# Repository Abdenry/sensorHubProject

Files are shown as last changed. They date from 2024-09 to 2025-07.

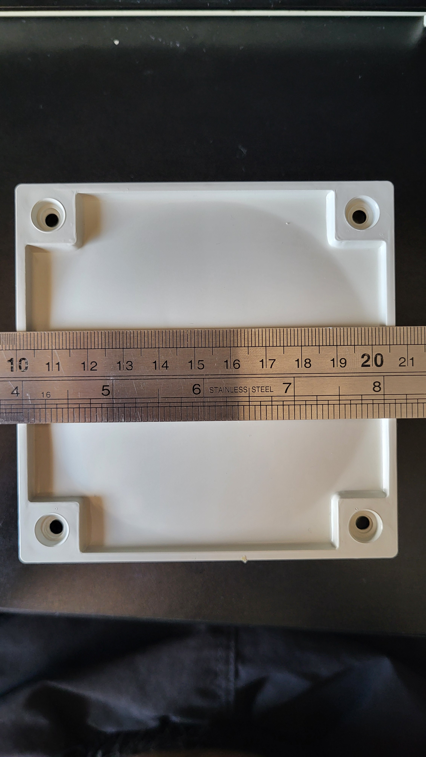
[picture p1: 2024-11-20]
CAD/FreeCAD/weatherStation/components/conduit/box/20241117_103729.jpg

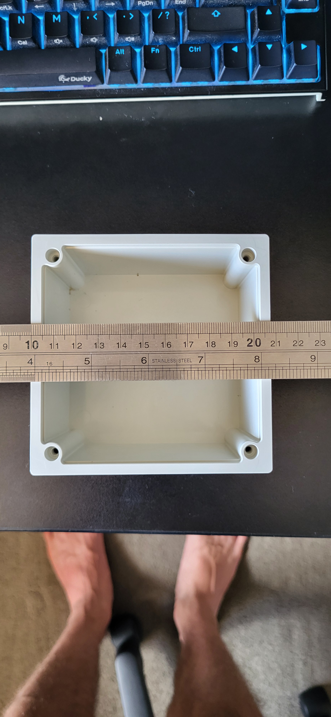
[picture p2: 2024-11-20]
CAD/FreeCAD/weatherStation/components/conduit/box/20241117_102943.jpg

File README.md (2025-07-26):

# Sensor Hub

<p align="center">
  weatherStation
</p>

A small, portable, self-sustaining weather station built to provide data to an external web interface hosted with Grafana via a Raspberry Pi Zero 2 W. This station is able to collect various metrics from on board sensors such as temperature, humidity, heat index, wind speed, and wind direction. A **DHT22** sensor is used to collect relative humidity and temperature metrics with an accuracy of +-2% and +-0.5C, while metrics such as wind speed and wind direction are collected with custom built sensors. The heat index is calculated in software using the [DHT-sensor-library](https://github.com/adafruit/DHT-sensor-library).

Communication is handled through the NRF24l01 radio modules in a mesh configuration. The mesh routing of data packets is automatically managed with `RF24.h`, `RF24Network.h`, and `RF24Mesh.h` provided by the [RF24](https://github.com/nRF24/RF24?tab=readme-ov-file) library, specifically chosen for its meshing capabilities. It provides dynamic configuration of the NRF24l01 modules, meaning that in the scenario where the weather station loses connection with the Raspberry Pi for any reason (power down, range lost, etc.), it can automatically reconfigure and connect to the Raspberry Pi given its under normal operable condition (i.e. has power and is in range). This allows additional stations to be installed with potentially different purposes with all metrics collected to be routed back to the Raspberry Pi. Alternatively, if the distance between the Raspberry Pi and the weather station is much greater than the range of a single NRF24l01 module, an additional node can be configured and placed in between the weather station and Raspberry Pi acting as a range extender. The RF24 library will automatically handle the routing and pass the data collected from the weather station to the Raspberry Pi via that additional node. There is no limitation that prevents an additional station from also being a range extending node.

<p align="center">
  nrf24WeatherStationDiagram4
</p>

### Wiring Diagram
<p align="center">
  circuitDiagram3
</p>

### CAD Model
<p align="center">
  weatherStationCAD
</p>

## Sensor Design
The following sensor assemblies were all 3D printed out of white PET-G filament for its UV resistance, and to reflect as much heat as possible to avoid compromising the temperature and humidity readings of the DHT22 sensor.
### Solar Radiation Shield
The DHT22 sensor used to collect temperature and humidity data was housed in a solar radiation shield. This is necessary to prevent direct sunlight from heating the sensor over time creating higher than ambient temperature readings, simultaneously it protects the sensor from rainfall, which would also cause a higher than ambient humidity reading if it gets wet.

### Wind Vane
Wind direction was measured using eight AH180 omni-polar hall effect sensors and a magnet on the underside of the vane. Each hall effect sensor acts as one of the four cardinal or ordinal directions (North, North East, East, etc.) which is activated only in the presence of the magnet. The vane will point in the direction the wind is blowing **from**. With limited IO available on the Arduino Nano/ATmega328p the SN74HC175N Parallel In Serial Out (PISO) Shift Register was used to reduce the eight outputs of the wind vane to one output + three inputs, halving the total amount of connections to the Arduino Nano/ATmega328p.

<p align="center">
  windVane
</p>

### Anemometer
Wind speed was measured using two magnets and a single US1881 latching hall effect sensor connected to the Arduino Nano D2 pin which corresponds to the ATmega328p external interrupt pin 0 (PD2). The magnets attached to the underside of the anemometer rotate over the US1881 sensor triggering either a high or low state depending on the magnets polarity, generating an interrupt which increments a revolution counter. The `getWindSpeed()` function is called periodically to calculate the wind speed using the amount of revolutions counted within that period, resetting the revolution counter once calculation has completed, and repeats this process. This assembly was tested by having the anemometer attached externally to a moving car, logging its calculated wind speed and comparing it to that the vehicles actual speed. It proved accurate to +-2 km/h with a vehicle speed of 80 km/h.
<p align="center">
  anemometer
</p>

## Grafana Dashboard
The Grafana dashboard conveniently displays historical readings for temperature, humidity, wind speed, and direction. It also provides an updated reading of the stations current temperature, humidity, and calculated heat index. The dashboard has been configured to retain this information for up to two weeks however this can be further increased if desired.
<p align="center">
  dashboard
  successfulTransmission
</p>

## Power Supply and Challenges Faced
Power for the station comes from a 1100 mAh LiPo battery, supported by four 1W solar panels connected in parallel. A solar power manager with Maximum Power Point Tracking (MPPT) is implemented to maximise the efficiency of the solar panels, switching between charging the station and its battery based on sunlight availability. It ensures that the battery remains charged during daylight hours, with enough capacity to keep the station operational overnight. After optimisations, the weather station consumes approximately 0.021 A at 3.72 V, providing an estimated 52 hours of operation without any solar input.

Prior to optimising power consumption, a major challenge faced during development was the intermittent loss of communications particularly over night.

<p align="center">
  dropOuts
</p>

Initially, it was suspected that the issue was not related to power due to the assumption that the 4 watt solar panel array was capable of powering and charging the station which had a measured active consumption of 0.24W (65mA @ 3.7V). After investigating the issue for a significant period of time, no definitive answer could explain the intermittent communication loss overnight other than insufficient solar power. To prove this was the root of the problem the station was connected to a bench top power supply with a constant 3.7V over night. This resulted in no communication drop outs over night nor for the next couple of days as the battery was sufficiently charged from the constant 3.7 V provided by the power supply. Optimisations for the code then proceeded to lower the active consumption.

### Optimisations
The first optimisation was replacing the software timer used to intermittently send weather metrics to the Raspberry Pi to a Watchdog Timer. This did not directly improve the power consumption of the station, however, it would allow the station to wake up from a power down mode, which was the second optimisation performed.

Entering the Arduino Nano/ATmega328p into a power down mode and only powering up after the Watchdog Timer expired directly reduced power consumption from 0.24W (65mA @ 3.7V) to 0.208W (56mA @ 3.7V), a 13% power efficiency improvement.

This was further improved by 64% by powering down the NRF24l01 radio module when not in use. This lowered the active consumption of the station to just 0.0744W (20mA @ 3.7V). This is a total 69% improvement from the initial 0.24W (65mA @ 3.7V) observed prior to optimising.

With the stations active power consumption optimised, the 4W solar panel array was able to sufficiently charge and power the station eliminating the intermittent communication loss.

## Future Improvements
- This station could be improved in the future with the inclusion of a rainfall sensor to collect metrics on the volume and rate of rainfall. One possible design for this sensor could involve a tipping bucket mechanism, where a known volume of rain causes a bucket to tip, triggering a hall-effect sensor to log the event. By counting the frequency of tipping, the system could accurately measure rate and cumulative rainfall over time.
- Improvements could also be made to the assembly of the custom sensors to be more accessible for servicing as the current design is finicky to put together, not suitable for consistently taking apart and putting back together.
- The internal wiring of the station could also be significantly improved by switching the single core wire used for **each** connection, to a multi-core cable. This could make the internal wiring much tidier and easier to access/service.

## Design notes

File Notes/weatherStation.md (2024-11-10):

# Weather Station

The goal is to create an affordable meteorological station for homeowners. This station will enable users to conduct informal studies on local weather patterns, identify optimal gardening techniques, and predict weather events to better prepare for potential threats to their homes.

The station will have a myriad of sensors used to identify the correct weather trends and are listed in detail below. The goal is to construct a weather station for less then cheap commercially [available options](https://www.bunnings.com.au/holman-aspect-wireless-data-centre-weather-station_p3110644).

## Functionality

| Atmospheric Conditions | Sensor |
| --- | --- |
| The weather station shall measure Dry Ambient Temperature. | (ASAIR - AHT20) |
| The weather station shall measure Percent Relative Humidity. | (ASAIR - AHT20) |
| The weather station shall measure Atmospheric Pressure. | (ST - LPS331AP) |

| Wind Measurements | Sensor |
| --- | --- |
| The weather station shall measure Wind Speed. | (Diodes Corporate - AH180) |
| The weather station shall measure Wind Direction. | (Diodes Corporate - AH180) |

| [Precipitation Monitoring](https://smartsolutions4home.com/ss4h-rg-rain-gauge/) | Sensor |
| --- | --- |
| The weather station shall measure Rate of Rainfall. | (Diodes Corporate - AH180) |
| The weather station shall measure Amount of Rainfall. | (Diodes Corporate - AH180) |

| Severe Weather Detection | Sensor |
| --- | --- |
| The weather station should detect lightning strikes. | TBD |

## Design

| Radiation Shield                                                                                                                                                                                                                                                                                                                                                                                                   |
| ------------------------------------------------------------------------------------------------------------------------------------------------------------------------------------------------------------------------------------------------------------------------------------------------------------------------------------------------------------------------------------------------------------------ |
| Both the humidity and temperature sensors will be contained within a radiation shield. This is to prevent direct and indirect heat sources compromising the reliability/accuracy of the senors. It also acts to shield the sensor against rain and fog. [Learn More](https://www.instrumentchoice.com.au/news/instrument-choice-experiment-what-is-the-function-of-a-solar-radiation-shield-on-a-weather-station). |

| Microcontroller                                                                                                                                                                            |
| ------------------------------------------------------------------------------------------------------------------------------------------------------------------------------------------ |
| The microcontroller will be contained in a waterproof container. Any connections made between the microcontroller that is outside the container, will be waterproof and weather resistent. |

| Materials                                                                                                                                                                   |
| --------------------------------------------------------------------------------------------------------------------------------------------------------------------------- |
| Materials used in the design will be durable to the Australia weather. Materials should be UV resistant and should have a heat deflection rating higher than $55\degree$ C. |

| Power |
| ----- |
| A battery will be used to power the device and sensors. The battery will be contained within a water proof container with any connections between it and devices outside the container, waterproof and weather resistent. The battery will be rechargeable via a solar panel mounted to the weather station. |

## Notes

- The chosen [magnets](https://www.digikey.com.au/en/products/detail/radial-magnets-inc/8015/15276818) to be used have been calculated based on the surface Gauss rating and the AH180 operation specs outlined in the datasheet. The information while not rigorous, has been marked against this [calculator](https://www.kjmagnetics.com/calculator.asp?calcType=disc),
  and hand calculated based on the inverse square law. Noting that for both the calculator and [datasheet](https://docs.rs-online.com/c755/0900766b813e101b.pdf) for a similar magnet with a defined Gauss rating at ~1mm. Both seemed to lose ~40% of strength @ 1mm from surface rating.
  Using this as a basis for the chosen magnets it was estimated that at 1mm from surface would have a Gauss rating of ~1335.5, following the inverse square law with this in mind, it was estimated that at 5 mm from the surface of the chosen magnet it would have a strength of ~53.42 Gauss.
  This should be sufficient for the AH180 operation.

- There are two method to measure apparent temperature; one with solar radiance and one without. Both require the dry ambient temperature, the relative humidity percent, and wind speed (m/s). The wind speed needs to be measured at an elevation of 10 meters.

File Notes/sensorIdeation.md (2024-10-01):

# Sensors For Hub
Ideation, hardware, and research for various sensors to potentially be used for the sensorHub project. 

List of sensor ideas:
- Garage Door Sensor
- Outside sensor hub:
   - Barometer
   - Anemometer (Wind Speed Gauge)
   - Temperature Sensor
   - Humidity Sensor
- Moisture Sensor (for plants)
- Daylight sensor
- PC Sensor
- Smart Door Locks
- Water leak sensors

## Garage Door Sensor
Simple sensor that detects if a garage door is currently open or closed. Detection can be achieved via ultrasonic sensor that relays a true or false if the door is open or closed.

## Outside Sensor hub
A hub that can measure the outside temperature, wind speed, humidty and atmospheric pressure.

## Moisture Sensor
A simple sensor that can be used across multiple pot plants or garden beds to determine if watering is needed.

## Daylight Sensor
A simple sensor used to determine if it is day or not. By itself not particularly useful but can be used in conjuction with other devices to turn appliances on/off.

## PC Sensor
A remote switch for a PC that indicates the current state of the PC (on/off) and can be powered on/off remotely.

## Smart Door Locks
A sensor that detects if doors have been locked after you have left the house (Similar to garage door sensor).

## Water leak sensors
Sensors that detect water leakage in areas that are critical and cannot be wet. This can be used in other sensors or appliances around the house.

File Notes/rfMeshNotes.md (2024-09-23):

# [Mesh Networking for RF24 (RF24Mesh)](https://nrf24.github.io/RF24Mesh/md_docs_2general__usage.html)

- Automates the networking process of nrf24 modules
- Assigns nodes a unique number ranging from 1 to 255 (user defined) to act as a static IP
- Addressing, routing, etc. is handled by the library
- Master node keeps track of unique IDs and assigned RF24Network addresses
- Moved or disconnected nodes can automically rejoin the mesh and reconfigure within network
- Uses functionality from RF24 and RF24Network libraries

## [General Usage](https://nrf24.github.io/RF24Mesh/md_docs_2general__usage.html)

### Network Design Options

1. Static Network (no mesh)

   - RF24Network manually configured with static design. RF24Mesh is not used.

2. Static network w/Dynamic Assignment

   - RF24Mesh is only used to acquire an address on startup
   - Nodes are expected to remain stationary
   - Changes to network addressed manually by adding, removing, or resetting nodes
   - Can use the RF24Network functions directly or use RF24Mesh

3. Dynamic Network & Assignment

   - Nodes join the mesh automatically and re-attach as required.
   - Default setting (used for examples)

4. Hybrid Network

   - Utilizes a combination of static & dynamic nodes
   - Requires initlal planning and deployment
   - Can be more stable network easing the use of sleeping nodes

### Network Management

- RF24Network addresses can be viewed as MAC addresses
- RF24Mesh NodeIDs viewed as static IP addresses
- When joining or re-joining network nodes will request a RF24Network address, and are identified via nodeID

#### Raspberry Pi/Linux

- RF24Gateway saves address assignments to file `dhcplist.txt` for restoration even if gateway is restarted
- To force network re-convergence, delete `dhcplist.txt` and restart gateway
- If nodes are configured t overify their connection at set intervals they will come back online in time

#### Arduino/AVR

- Address list is not saved
- To force network re-convergence, restart gateway.
- If nodes are configured t overify their connection at set intervals they will come back online in time
- if node/nodeID is removed permanently, the address hsould be releaser **prior** to removal

### Mesh Communication

- RF24Mesh nodeIDs are unique identifiers
- RF24Network addresses change dynamically within statically defined structure
  - All nodes know the master address (00)
  - The master node maintains a list of all nodes (immediate address lookups)
- Node to Node communication requires address queries to be sent to master node
  - Inheritently inefficient

### Tricks of Trade

- For nodes constantly transmitting (every few seconds at most) it is suitable to check the connection, and/or renew the address when conenctivity fails. Data is not saved by the master node, if the master node goes down, all child nodes must renew their address. In this case, as long as the master node is down for a few seconds, the nodes will all begin requesting an address.
- Nodes not actively transmitting, should be configured to test their connection at predefined intervals to allow them to reconnect as necessary
- Sleeping nodes (nodes only temporarily online) should release their address prior to going offline and request a new one upon waking. _(Note: This can take 10 - 15 ms, up to a few seconds)_
- When transmitting payloads without the network returning a ack-response, nodes should be configured to periodically check connection using `RF24Mesh::checkConnection()`

### RF24Network

Beyond requesting and releasing addresses, usage is outlined in the [RF24Mesh class documentation](https://nrf24.github.io/RF24Mesh/annotated.html), and further information regarding RF24Network is available at [RF24Network documentation](https://nrf24.github.io/RF24Network/index.html).

## [Setup and Config](https://nrf24.github.io/RF24Mesh/md_docs_2setup__config.html)

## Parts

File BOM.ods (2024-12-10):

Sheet: Master Node
Sensor Hub: Bill of Materials
Master Node
Part # | Part Name | Quantity | Units Per Package | Part Description | Package | Vendor | Vendor SKU | Lead Time | Vendor Link | Datasheet | Unit Cost | Total Cost | Rev. Number | Notes
1 | Raspberry Pi Zero 2 W | 1 | 1 | Master Node | N/A | Core Electronics | CE08211 | N/A | Click Here (https://core-electronics.com.au/raspberry-pi-zero-2-w-wireless.html) | Click Here (https://datasheets.raspberrypi.com/rpizero2/raspberry-pi-zero-2-w-product-brief.pdf) | $29.50 | $29.50 | 1.0
2 | nRF24L01+ Module | 1 | 1 | RF Module | Breakout Board | Maker Zone | MZ672890NRFX1 | N/A | Click Here (https://makerzone.com.au/product/nrf24l01/) | Click Here (https://cdn.sparkfun.com/datasheets/Wireless/Nordic/nRF24L01_Product_Specification_v2_0.pdf) | $7.76 | $7.76 | 1.0 | Base NRF24L01 is sufficient
3 | Official Raspberry Pi 12.5W Micro USB Power Supply | 1 | 1 | Power Supply | AU Plug | Core Electronics | CE08324 | N/A | Click Here (https://core-electronics.com.au/official-raspberry-pi-12-5w-micro-usb-power-supply.html) |  | $15.55 | $15.55 | 1.0
4 | Mini HDMI to Standard HDMI Jack Adapter (for Raspberry Pi Zero) | 1 | 1 | Adapter | HDMI | Core Electronics | CE04760 | N/A | Click Here (https://core-electronics.com.au/mini-hdmi-to-standard-hdmi-jack-adapter-for-raspberry-pi-zero.html) |  | $5.49 | $5.49 | 1.0
5 | AuviPal 3-Port Micro USB OTG Hub Adapter | 1 | 1 | Adapter | Micro USB | AuviPal | N/A | N/A | Click Here (https://www.amazon.com.au/AuviPal-Adapter-Playstation-Classic-Raspberry/dp/B083WML1XB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) |  | $23.50 | $32.50 | 1.0
6 | FLIRC Raspberry Pi Zero Case | 1 | 1 | Case | N/A | Core Electronics | CE07071 | N/A | Click Here (https://core-electronics.com.au/flirc-raspberry-pi-zero-case.html) |  | $20.95 | $20.95 | 1.0 | OPTIONAL
 |  |  |  |  |  |  |  |  |  |  |  |  | Sum: | $111.75

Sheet: Weather Station
Sensor Hub: Bill of Materials
Weather Station
Part # | Part Name | Quantity | Units Per Pack | Part Description | Package | Vendor | Vendor SKU | Lead Time | Vendor Link | Datasheet | Unit Cost | Total Cost | Rev. Number | Notes
1 | Fermion: AHT20 Temperature and Humidity Sensor (Breakout) | 1 | 1 | The AHT20 is a high-precision but low-cost temperature and humidity sensor | Breakout Board | Core Electronics | SEN0527 | N/A | Click Here (https://core-electronics.com.au/fermion-aht20-temperature-and-humidity-sensor-breakout.html) | Click Here (https://cdn-learn.adafruit.com/assets/assets/000/123/394/original/Data_Sheet_AHT20.pdf?1691532479) | $5.95 | $5.95 | 1.0
2 | LPS331AP Pressure/Altitude Sensor Carrier with Voltage Regulator | 1 | 1 | The LPS331AP is a high resolution, digital output pressure sensor packaged in an HCLGA holed package. | Breakout Board | Core Electronics | POLOLU-2126 | N/A | Click Here (https://core-electronics.com.au/lps331ap-pressure-altitude-sensor-carrier-with-voltage-regulator.html) | Click Here (https://core-electronics.com.au/attachments/localcontent/LPS331AP_4526900948c.pdf) | $6.40 | $6.40 | 1.0
3 | Diodes Incorporated Hall Effect Sensor Switch | 20 | 1 | AH180 is a micro-power omnipolar hall-effect sensor designed for portable and battery powered equipment. | SIP | DigiKey | 31-AH180-PG-ACT-ND | 8 Weeks | Click Here (https://www.digikey.com.au/en/products/detail/diodes-incorporated/AH180-PG-A/7802337) | Click Here (https://www.diodes.com/assets/Datasheets/AH180.pdf) | $0.75 | $14.98 | 1.0
4 | nRF24L01+ Module | 1 | 4 | RF Module | Breakout Board | Maker Zone | MZ672890NRFX1 | N/A | Click Here (https://makerzone.com.au/product/nrf24l01/) | Click Here (https://cdn.sparkfun.com/datasheets/Wireless/Nordic/nRF24L01_Product_Specification_v2_0.pdf) | $7.76 | $31.04 | 1.0
5 | Radial Magnets 8015 | 10 | 1 | 3mm x 1mm magnet for hall effect sensors | N/A | DigiKey | 469-8015-ND | 10 Weeks | Click Here (https://www.digikey.com.au/en/products/detail/radial-magnets-inc/8015/15276818) | Click Here (https://radialmagnet.com/wp-content/uploads/2017/03/SpecSheet-SKU-8015.pdf) | $0.39 | $3.88 | 1.0 | Should be strong enough to activate AH180 if distance is ≤ 5 mm
6 | Arduino Nano | 1 | 1 | Arduino Nano for processing sensor data | Breakout Board | Core Electronics | CE05101 | N/A | Click Here (https://core-electronics.com.au/nano-v3-0-board.html) | Click Here (https://core-electronics.com.au/attachments/uploads/CE05101_Datasheet.pdf) | $8.60 | $8.60 | 1.0
7 | 19 x 6 x 6mm Bearing | 1 | 4 | Bearings for the wind speed and direction sensor | N/A | Bunnings | 356554 | N/A | Click Here (https://www.bunnings.com.au/richmond-19-x-6-x-6mm-rubber-sealed-precision-bearing-4-pack_p0356554) | N/A | $1.38 | $5.50 | 1.0
8 | Conduit Adapter | 6 | 1 |  | N/A | Bunnings | 4330865 | N/A | Click Here (https://www.bunnings.com.au/deta-20mm-adaptor-with-lock-ring-20mm_p4330865) | N/A | $1.11 | $6.66 | 1.0
9 | Conduit Elbow | 1 | 1 |  | N/A | Bunnings | 4330793 | N/A | Click Here (https://www.bunnings.com.au/deta-25mm-conduit-elbow-bend_p4330793) | N/A | $1.70 | $1.70 | 1.0
10 | Conduit Inspection Tee | 1 | 1 |  | N/A | Bunnings | 4330801 | N/A | Click Here (https://www.bunnings.com.au/deta-25mm-inspection-tee-conduit_p4330801) | N/A | $2.66 | $2.66 | 1.0
11 | Weatherproof Junction Box | 1 | 1 |  | N/A | Bunnings | 4330859 | N/A | Click Here (https://www.bunnings.com.au/deta-108mm-weatherproof-junction-box-ip56-108-x-108-x-76mm_p4330859) | N/A | $13.36 | $13.36 | 1.0
12 | Melexis Through Hole Hall Effect Sensor | 1 | 10 | US1881: Latched hall-effect sensor | TO-92 | RS Components | 194-2962 | N/A | Click Here (https://au.rs-online.com/web/p/motion-sensor-ics/1942962?searchId=a58a7402-da3c-4acc-97b0-73d81d61bae4&gb=s) | Click Here (https://docs.rs-online.com/0c5f/A700000006488865.pdf) | $0.78 | $7.82 | 1.0 | Used for speed sensing
13 | SN74HC165N 8-bit Parallel-Load Shift Register | 1 | 25 | Shift register used in wind vane for cardinal directions | DIP | Amazon | N/A | N/A | Click Here (https://www.amazon.com.au/gp/product/B0D314YPZK/ref=ppx_od_dt_b_asin_title_s00?ie=UTF8&psc=1) | Click Here (https://www.ti.com/lit/ds/symlink/sn74hc165.pdf?ts=1732246880337) | $0.64 | $16.09 | 1.0
14 | Sunflower: Solar Power Manager 5V | 1 | 1 | Solar Power Manager with MPPT function. | Breakout Board | Core Electronics | DFR0559 | N/A | Click Here (https://core-electronics.com.au/sunflower-solar-power-manager-5v.html) | Click Here (https://wiki.dfrobot.com/Solar_Power_Manager_5V_SKU__DFR0559) | $12.95 | $12.95 | 1.0
15 | LM2596S Step-Down converter | 1 | 1 | Step down to protect solar manager from panel over voltage | Breakout Board | Core Electronics | CE05572 | N/A | Click Here (https://core-electronics.com.au/adjustable-switching-power-supply-module-in-4v-35v-out-1-5v-30v-lm2596s.html) | N/A | $3.05 | $3.05 | 1.0
16 | 1W 90x100 Solar Panel | 2 | 1 | Used to power weather station | N/A | Core Electronics | SS313070005 | N/A | Click Here (https://core-electronics.com.au/1w-solar-panel-80x100-seeed-studio.html) | N/A | $10.60 | $21.20 | 1.0
17 | LiPo 3.7V 1100mAh Battery | 1 | 1 | Used for night operations of weather station | N/A | Core Electronics | CE04377 | N/A | Click Here (https://core-electronics.com.au/polymer-lithium-ion-battery-1000mah-38458.html) | N/A | $10.50 | $10.50 | 1.0
18 | LD1117V33 3.3V Regulator | 1 | 1 | For 3.3V devices | TO-220 | Core Electronics | COM-00526 | N/A | Click Here (https://core-electronics.com.au/voltage-regulator-3-3v.html) | Click Here (https://core-electronics.com.au/attachments/localcontent/LD1117V33_100254b736f.pdf) | $3.50 | $3.50 | 1.0
19 | ALU Round Tube 20x1.6mm 1m | 2 | 1 |  | N/A | Bunnings | 427735 | N/A | Click Here (https://www.bunnings.com.au/metal-mate-20x1-6mm-1m-aluminium-round-tube-1m_p0427735) | N/A | $12.90 | $25.80 | 1.0
20 | Conduit Coupling | 1 | 1 |  | N/A | Bunnings | 4330872 | N/A | Click Here (https://www.bunnings.com.au/deta-20mm-conduit-coupling-single-pack_p4330872) | N/A | $0.30 | $0.30 | 1.0
21 |  |  |  |  |  |  |  |  |  |  |  | $0.00
22 |  |  |  |  |  |  |  |  |  |  |  | $0.00
23 |  |  |  |  |  |  |  |  |  |  |  | $0.00
 |  |  |  |  |  |  |  |  |  |  |  |  | Sum: | $201.94

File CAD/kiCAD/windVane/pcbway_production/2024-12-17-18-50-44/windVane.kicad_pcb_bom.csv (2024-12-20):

Designator | Quantity | Value | Footprint | Package | MPN | DNP | Mount_Type | Description
C1, C2, C3, C4, C5, C6, C7, C8 | 8 | 100nF | C_0402_1005Metric |  |  |  | smt | Unpolarized capacitor
East1, North1, NorthEast1, NorthWest1, South1, SouthEast1, SouthWest1, West1 | 8 | Conn_01x03 | PinHeader_1x03_P2.54mm_Vertical |  |  |  | tht | Generic connector, single row, 01x03, script generated (kicad-library-utils/schlib/autogen/connector/)
J1, J2 | 2 | Conn_01x01 | PinHeader_1x01_P2.54mm_Vertical |  |  |  | tht | Generic connector, single row, 01x01, script generated (kicad-library-utils/schlib/autogen/connector/)
R1, R2, R3, R4, R5, R6, R7, R8 | 8 | 10k | R_0402_1005Metric |  |  |  | smt | Resistor
SIG1 | 1 | Conn_01x06 | PinHeader_1x06_P2.54mm_Vertical |  |  |  | tht | Generic connector, single row, 01x06, script generated (kicad-library-utils/schlib/autogen/connector/)
SN74HC165 | 1 | Conn_02x08_Counter_Clockwise | DIP-16_W7.62mm |  |  |  | tht | Generic connector, double row, 02x08, counter clockwise pin numbering scheme (similar to DIP package numbering), script generated (kicad-library-utils/schlib/autogen/connector/)

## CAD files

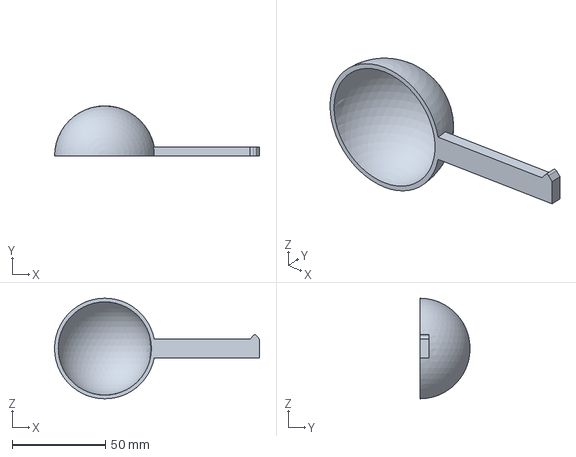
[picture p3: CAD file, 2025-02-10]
CAD/FreeCAD/weatherStation/anemometer/arm/arm.FCStd
110.0 x 27.0 x 54.0 mm

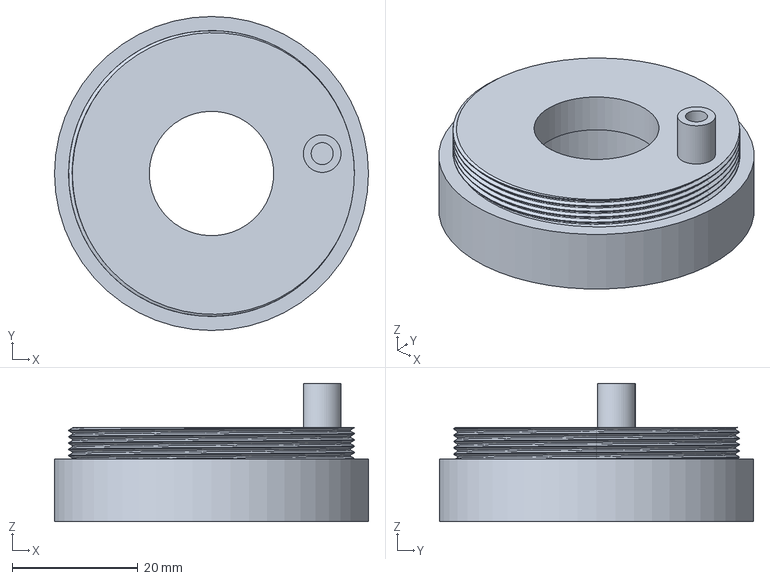
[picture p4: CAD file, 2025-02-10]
CAD/FreeCAD/weatherStation/anemometer/base/base.FCStd
50.0 x 50.0 x 22.0 mm

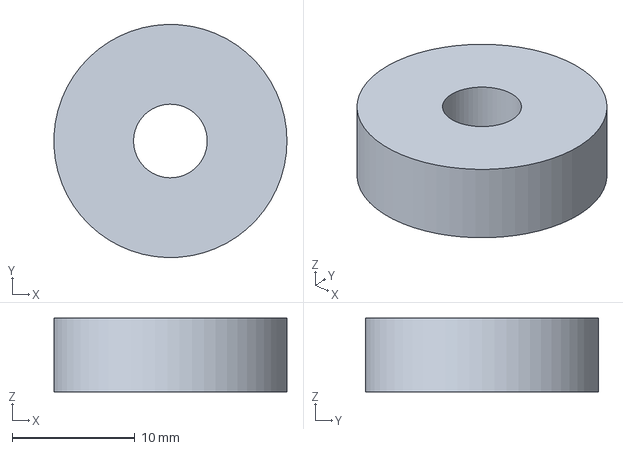
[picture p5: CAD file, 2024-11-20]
CAD/FreeCAD/weatherStation/anemometer/bearing/bearing.FCStd
19.0 x 19.0 x 6.00 mm

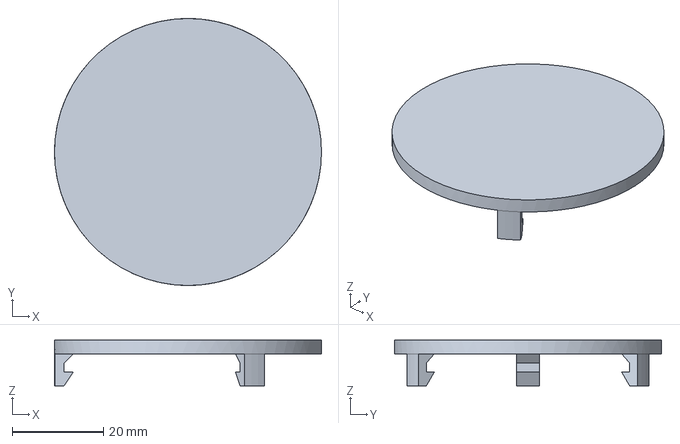
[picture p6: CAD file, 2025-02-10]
CAD/FreeCAD/weatherStation/anemometer/cover/cover.FCStd
58.5 x 58.5 x 10.0 mm

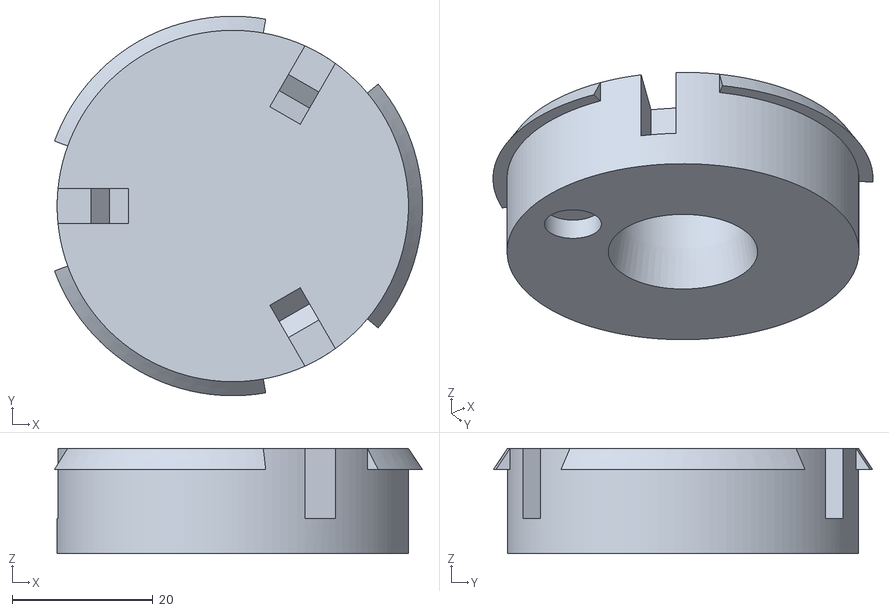
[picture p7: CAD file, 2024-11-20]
CAD/FreeCAD/weatherStation/anemometer/largerMagnet/top-Body.stl
52.4 x 54.0 x 15.0

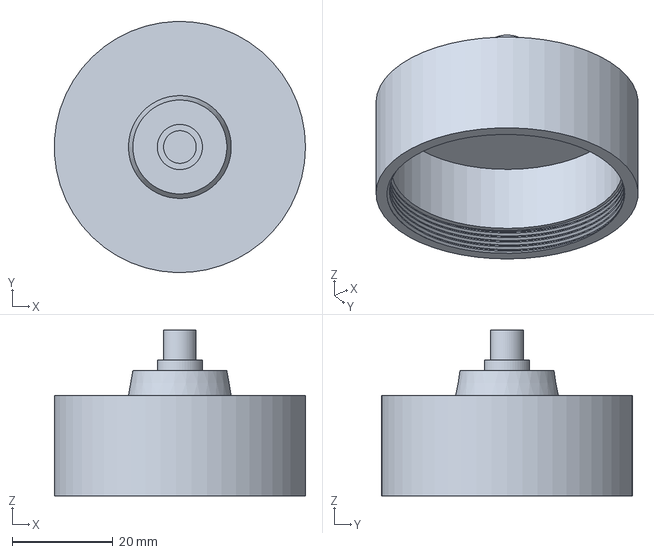
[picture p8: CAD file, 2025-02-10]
CAD/FreeCAD/weatherStation/anemometer/middle/middle.FCStd
50.0 x 50.0 x 33.0 mm

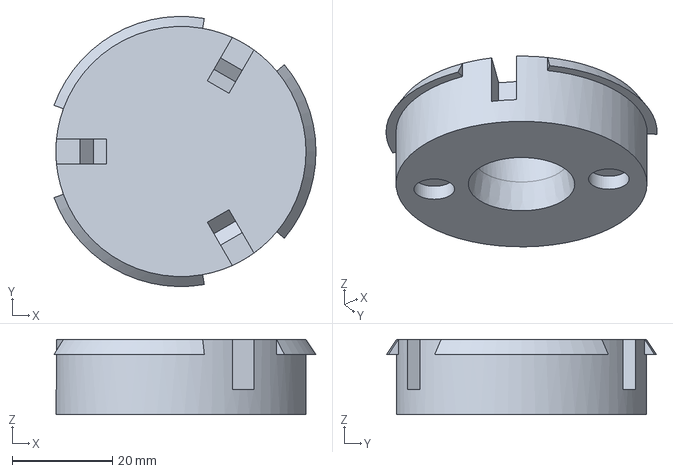
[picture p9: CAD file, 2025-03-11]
CAD/FreeCAD/weatherStation/anemometer/top/top.FCStd
52.4 x 54.0 x 15.0 mm

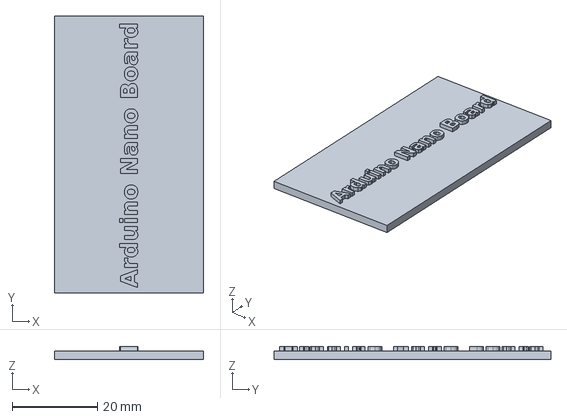
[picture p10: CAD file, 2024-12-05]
CAD/FreeCAD/weatherStation/arduinoNano/pcbBoardSize.FCStd
35.0 x 65.0 x 3.00 mm

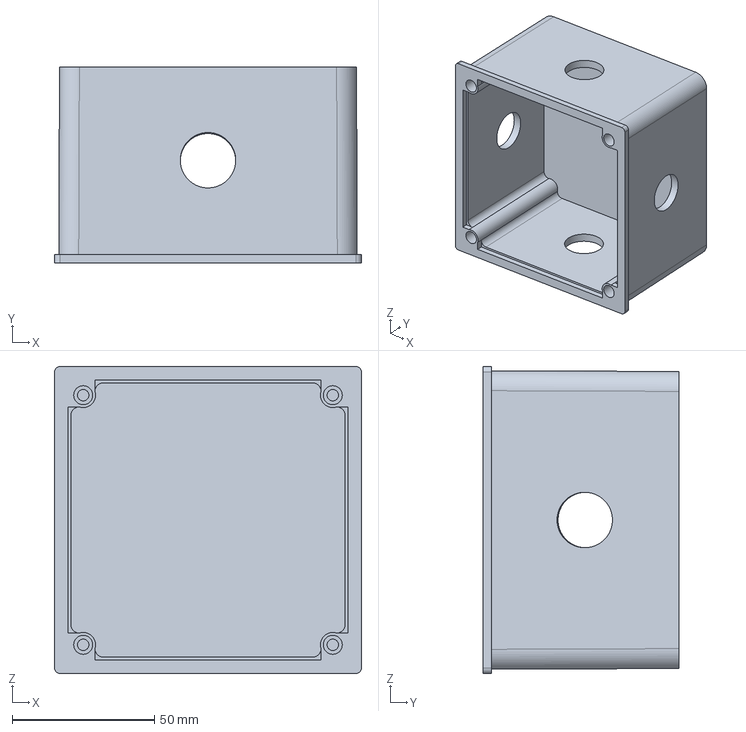
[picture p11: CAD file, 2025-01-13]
CAD/FreeCAD/weatherStation/components/conduit/box/container.FCStd
108.0 x 69.0 x 108.0 mm

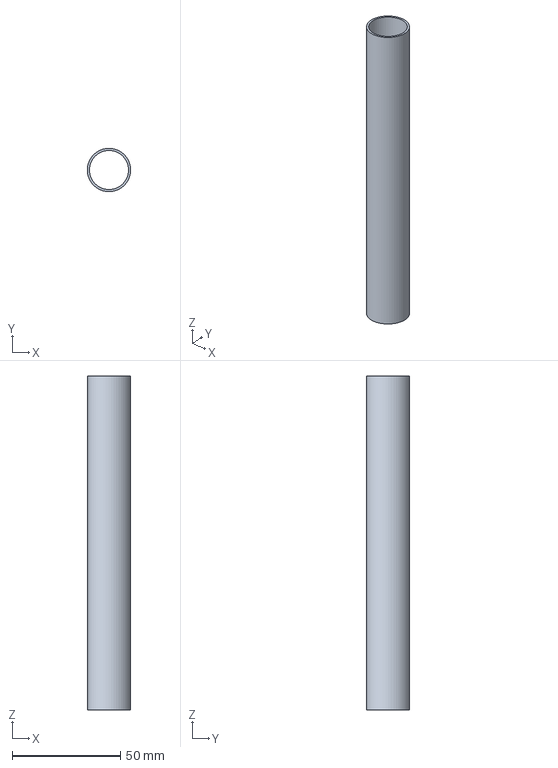
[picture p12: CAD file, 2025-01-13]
CAD/FreeCAD/weatherStation/components/conduit/straight150.FCStd
20.0 x 20.0 x 154.0 mm

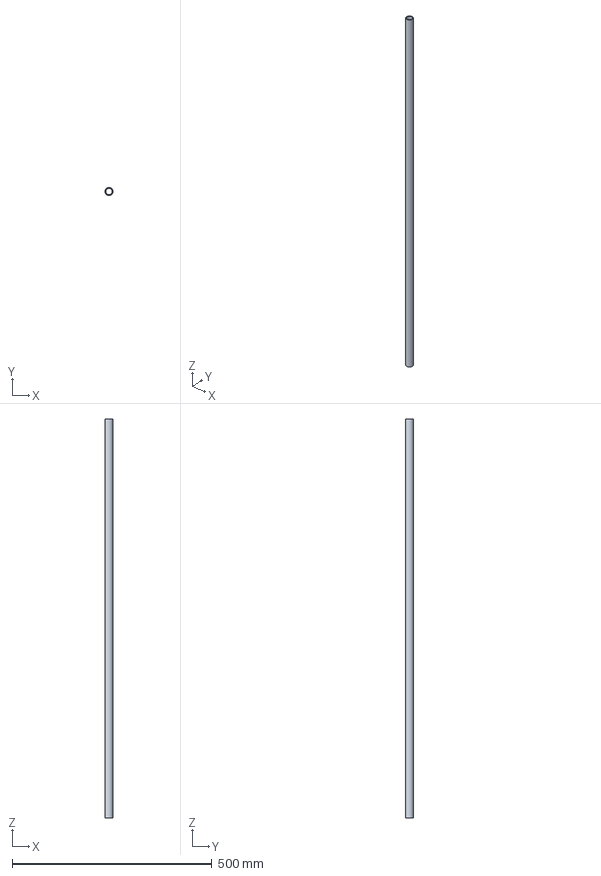
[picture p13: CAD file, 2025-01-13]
CAD/FreeCAD/weatherStation/components/stationPost.FCStd
20.0 x 20.0 x 1000.0 mm

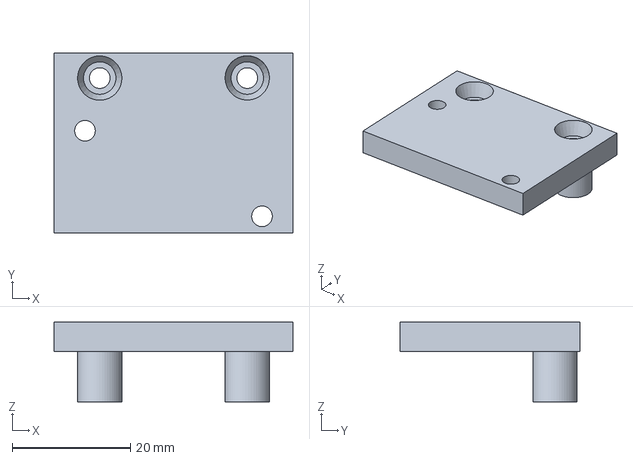
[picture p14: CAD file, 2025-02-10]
CAD/FreeCAD/weatherStation/powerSytem/5vStepDownStandoff2.FCStd
40.5 x 30.5 x 13.5 mm

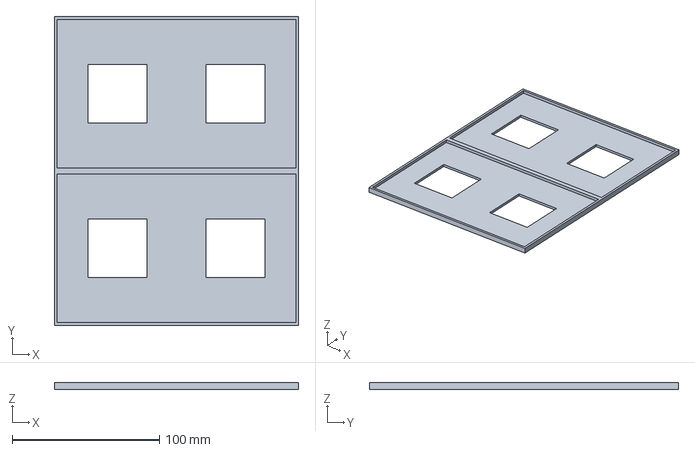
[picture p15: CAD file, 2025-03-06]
CAD/FreeCAD/weatherStation/solarPanel/solarBedFrame.FCStd
165.8 x 209.6 x 4.50 mm

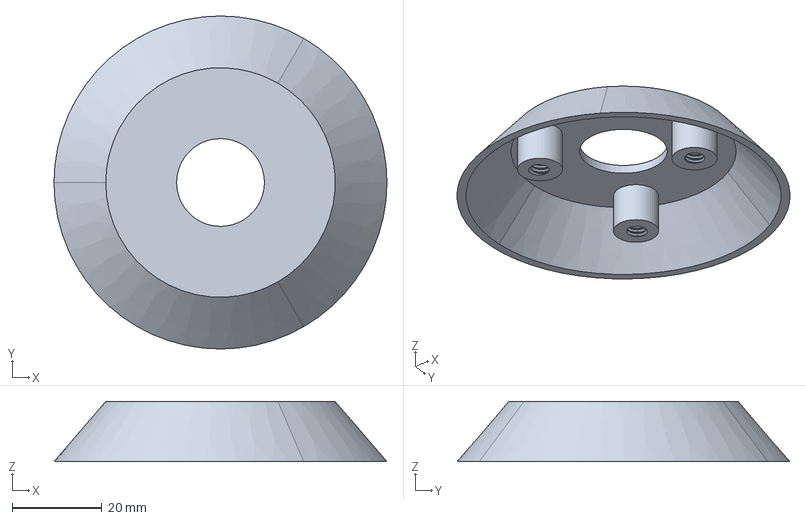
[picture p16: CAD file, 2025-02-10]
CAD/FreeCAD/weatherStation/solarRadiationShield/top.FCStd
74.0 x 74.0 x 13.4 mm

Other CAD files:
CAD/FreeCAD/weatherStation/anemometer/assembley.FCStd
CAD/FreeCAD/weatherStation/stationAssembly.FCStd
CAD/FreeCAD/weatherStation/windVane/assembly.FCStd
CAD/FreeCAD/weatherStation/solarPanel/ASSEMBLYsolar.FCStd
CAD/FreeCAD/weatherStation/anemometer/arm/arm-Body.stl
CAD/FreeCAD/weatherStation/anemometer/bearing/bearingTestFitInner-Body.stl
CAD/FreeCAD/weatherStation/anemometer/bearing/bearingTestFitInner.FCStd
CAD/FreeCAD/weatherStation/anemometer/bearing/bearingTestFitOuter-Body.stl
CAD/FreeCAD/weatherStation/anemometer/bearing/bearingTestFitOuter.FCStd
CAD/FreeCAD/weatherStation/anemometer/cover/cover-Body.stl
CAD/FreeCAD/weatherStation/anemometer/cover/cover-Cover.stl
CAD/FreeCAD/weatherStation/anemometer/top/top-Body.stl
CAD/FreeCAD/weatherStation/anemometer/top/top-Top.stl
CAD/FreeCAD/weatherStation/arduinoNano/pcbBoardSize.stl
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

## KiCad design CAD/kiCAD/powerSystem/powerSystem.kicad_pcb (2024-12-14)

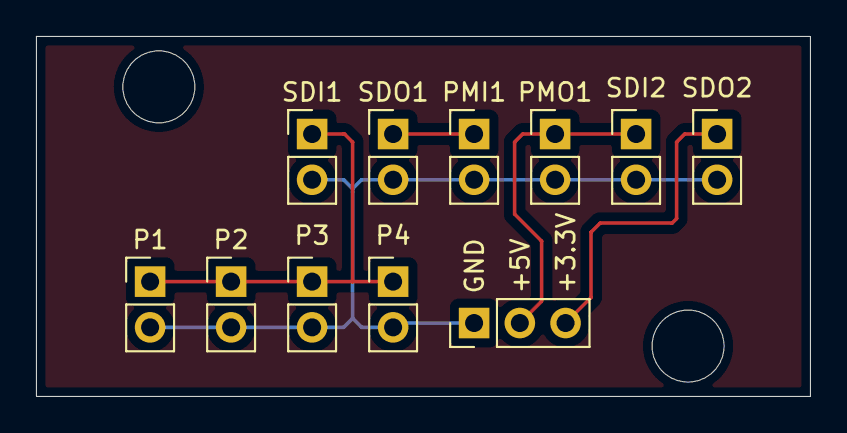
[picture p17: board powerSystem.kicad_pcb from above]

Board: 2 copper layers, 43.0 x 20.0 mm, 11 parts (0 on the bottom side), 5 nets.

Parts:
P1, P2, P3, P4: Conn_01x02; PinHeader_1x02_P2.54mm_Vertical
PMI1: Conn_01x02; PinHeader_1x02_P2.54mm_Vertical
PMO1: Conn_01x02; PinHeader_1x02_P2.54mm_Vertical
SDI1, SDI2: Conn_01x02; PinHeader_1x02_P2.54mm_Vertical
SDO1, SDO2: Conn_01x02; PinHeader_1x02_P2.54mm_Vertical
SIGOUT1: Conn_01x03; PinHeader_1x03_P2.54mm_Vertical

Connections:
/0~10V: P1.1, P2.1, P3.1, P4.1, SDI1.1
/+3_3V: SDO2.1, SIGOUT1.3
/+5.5V: PMI1.1, SDO1.1
/+5V: PMO1.1, SDI2.1, SIGOUT1.2
/GND: P1.2, P2.2, P3.2, P4.2, PMI1.2, PMO1.2, SDI1.2, SDI2.2, SDO1.2, SDO2.2, SIGOUT1.1

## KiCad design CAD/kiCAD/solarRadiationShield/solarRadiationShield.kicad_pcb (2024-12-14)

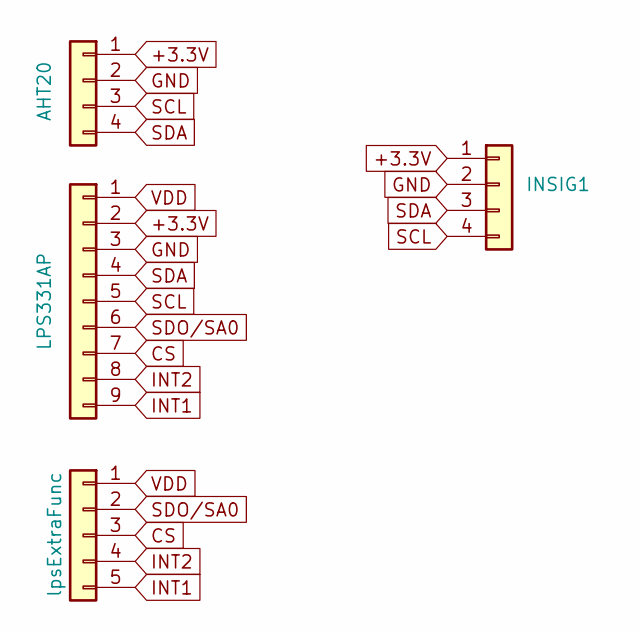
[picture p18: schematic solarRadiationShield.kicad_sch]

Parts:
AHT20: AHT20; PinHeader_1x04_P2.54mm_Vertical
INSIG1: INSIG; PinHeader_1x04_P2.54mm_Vertical
LPS331AP1: LPS331AP; PinHeader_1x09_P2.54mm_Vertical
lpsExtraFunc1: lpsExtraFunc; PinHeader_1x05_P2.54mm_Vertical

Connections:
+3.3V: AHT20.1, INSIG1.1, LPS331AP1.2
CS: LPS331AP1.7, lpsExtraFunc1.3
GND: AHT20.2, INSIG1.2, LPS331AP1.3
INT1: LPS331AP1.9, lpsExtraFunc1.5
INT2: LPS331AP1.8, lpsExtraFunc1.4
SCL: AHT20.3, INSIG1.4, LPS331AP1.5
SDA: AHT20.4, INSIG1.3, LPS331AP1.4
SDO/SA0: LPS331AP1.6, lpsExtraFunc1.2
VDD: LPS331AP1.1, lpsExtraFunc1.1

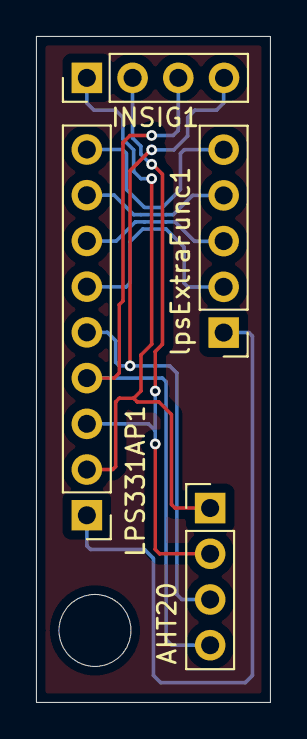
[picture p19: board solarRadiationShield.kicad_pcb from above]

Board: 2 copper layers, 13.0 x 37.0 mm, 4 parts (0 on the bottom side), 9 nets.

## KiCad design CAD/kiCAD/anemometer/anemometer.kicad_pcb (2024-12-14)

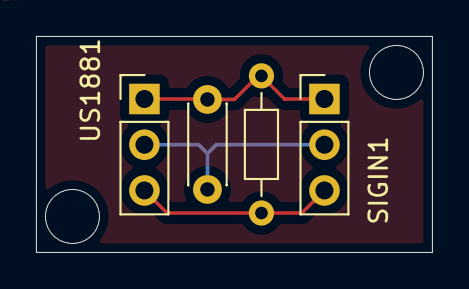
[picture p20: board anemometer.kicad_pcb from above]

Board: 2 copper layers, 22.0 x 12.0 mm, 4 parts (0 on the bottom side), 3 nets.

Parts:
C1: 100nF; C_Disc_D4.3mm_W1.9mm_P5.00mm
R1: 10k; R_Axial_DIN0204_L3.6mm_D1.6mm_P7.62mm_Horizontal
SIGIN1: Conn_01x03; PinHeader_1x03_P2.54mm_Vertical
US1881: Conn_01x03; PinHeader_1x03_P2.54mm_Vertical

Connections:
GND: C1.1, SIGIN1.2, US1881.2
OUT: R1.2, SIGIN1.3, US1881.3
VDD: C1.2, R1.1, SIGIN1.1, US1881.1

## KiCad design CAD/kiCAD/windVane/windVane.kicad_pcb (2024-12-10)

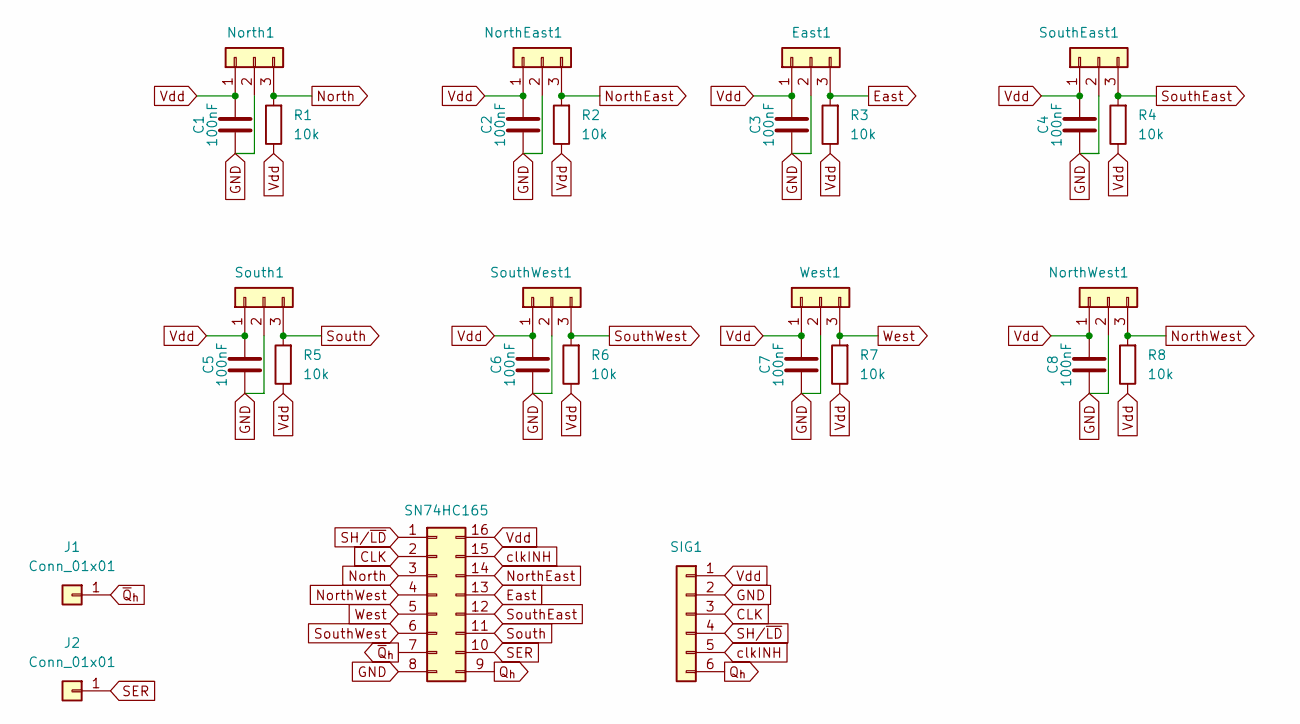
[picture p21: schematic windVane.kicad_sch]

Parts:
C1, C2, C3, C4, C5, C6, C7, C8: 100nF; C_0402_1005Metric
East1: Conn_01x03; PinHeader_1x03_P2.54mm_Vertical
J1, J2: Conn_01x01; PinHeader_1x01_P2.54mm_Vertical
North1: Conn_01x03; PinHeader_1x03_P2.54mm_Vertical
NorthEast1: Conn_01x03; PinHeader_1x03_P2.54mm_Vertical
NorthWest1: Conn_01x03; PinHeader_1x03_P2.54mm_Vertical
R1, R2, R3, R4, R5, R6, R7, R8: 10k; R_0402_1005Metric
SIG1: Conn_01x06; PinHeader_1x06_P2.54mm_Vertical
SN74HC165: Conn_02x08_Counter_Clockwise; DIP-16_W7.62mm
South1: Conn_01x03; PinHeader_1x03_P2.54mm_Vertical
SouthEast1: Conn_01x03; PinHeader_1x03_P2.54mm_Vertical
SouthWest1: Conn_01x03; PinHeader_1x03_P2.54mm_Vertical
West1: Conn_01x03; PinHeader_1x03_P2.54mm_Vertical

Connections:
CLK: SIG1.3, SN74HC165.2
East: East1.3, R3.2, SN74HC165.13
GND: C1.1, C2.1, C3.1, C4.1, C5.1, C6.1, C7.1, C8.1, East1.2, North1.2, NorthEast1.2, NorthWest1.2, SIG1.2, SN74HC165.8, South1.2, SouthEast1.2, SouthWest1.2, West1.2
North: North1.3, R1.2, SN74HC165.3
NorthEast: NorthEast1.3, R2.2, SN74HC165.14
NorthWest: NorthWest1.3, R8.2, SN74HC165.4
Q_{h}: SIG1.6, SN74HC165.9
SER: J2.1, SN74HC165.10
SH/~LD: SIG1.4, SN74HC165.1
South: R5.2, SN74HC165.11, South1.3
SouthEast: R4.2, SN74HC165.12, SouthEast1.3
SouthWest: R6.2, SN74HC165.6, SouthWest1.3
Vdd: C1.2, C2.2, C3.2, C4.2, C5.2, C6.2, C7.2, C8.2, East1.1, North1.1, NorthEast1.1, NorthWest1.1, R1.1, R2.1, R3.1, R4.1, R5.1, R6.1, R7.1, R8.1, SIG1.1, SN74HC165.16, South1.1, SouthEast1.1, SouthWest1.1, West1.1
West: R7.2, SN74HC165.5, West1.3
clkINH: SIG1.5, SN74HC165.15
~Q_{h}: J1.1, SN74HC165.7

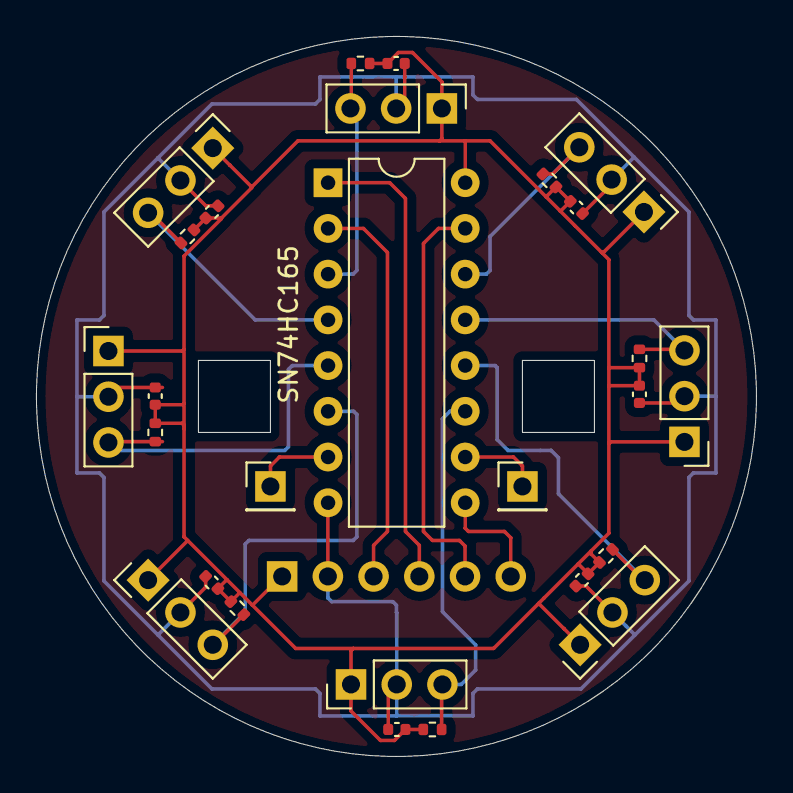
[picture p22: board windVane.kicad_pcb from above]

Board: 2 copper layers, 40.0 x 40.0 mm, 28 parts (1 on the bottom side), 16 nets.

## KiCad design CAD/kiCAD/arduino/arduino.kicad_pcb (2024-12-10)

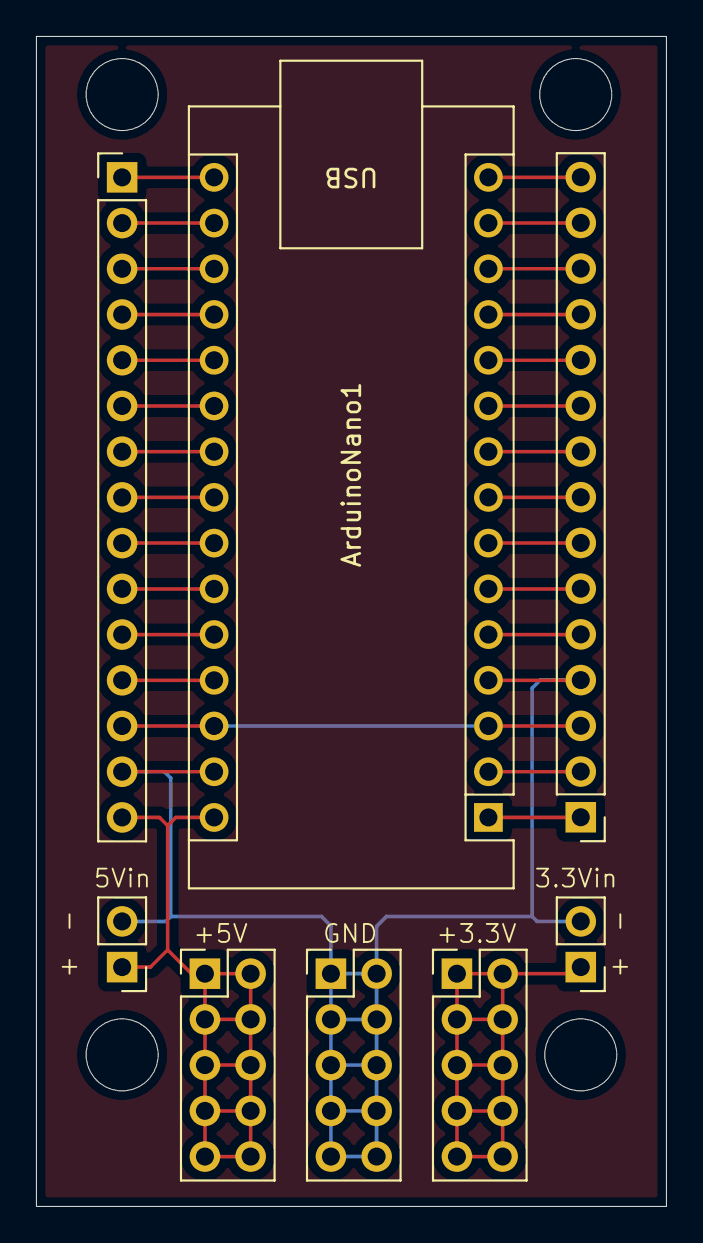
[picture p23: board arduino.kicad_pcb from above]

Board: 2 copper layers, 35.0 x 65.0 mm, 8 parts (0 on the bottom side), 29 nets.

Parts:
3.3Vbar1, 5Vbar1: Conn_02x05_Counter_Clockwise; PinHeader_2x05_P2.54mm_Vertical
5Vin1: Conn_01x02; PinHeader_1x02_P2.54mm_Vertical
ArduinoNano1: Arduino_Nano_v3.x; Arduino_Nano
Expansion1, Expansion2: Conn_01x15; PinHeader_1x15_P2.54mm_Vertical
GNDBar1: Conn_02x05_Counter_Clockwise; PinHeader_2x05_P2.54mm_Vertical
powerIN2: Conn_01x02; PinHeader_1x02_P2.54mm_Vertical

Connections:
+3.3V: 3.3Vbar1.1, 3.3Vbar1.2, 3.3Vbar1.3, 3.3Vbar1.4, 3.3Vbar1.5, 3.3Vbar1.6, 3.3Vbar1.7, 3.3Vbar1.8, 3.3Vbar1.9, 3.3Vbar1.10, powerIN2.1
+5V: 5Vbar1.1, 5Vbar1.2, 5Vbar1.3, 5Vbar1.4, 5Vbar1.5, 5Vbar1.6, 5Vbar1.7, 5Vbar1.8, 5Vbar1.9, 5Vbar1.10, 5Vin1.1, ArduinoNano1.30 (VIN), Expansion2.15
A0: ArduinoNano1.19 (A0), Expansion2.4
A1: ArduinoNano1.20 (A1), Expansion2.5
A2: ArduinoNano1.21 (A2), Expansion2.6
A3: ArduinoNano1.22 (A3), Expansion2.7
A4: ArduinoNano1.23 (A4), Expansion2.8
A5: ArduinoNano1.24 (A5), Expansion2.9
A6: ArduinoNano1.25 (A6), Expansion2.10
A7: ArduinoNano1.26 (A7), Expansion2.11
AREF: ArduinoNano1.18 (AREF), Expansion2.3
D0: ArduinoNano1.2 (D0/RX), Expansion1.2
D1: ArduinoNano1.1 (D1/TX), Expansion1.1
D2: ArduinoNano1.5 (D2), Expansion1.5
D3: ArduinoNano1.6 (D3), Expansion1.6
D4: ArduinoNano1.7 (D4), Expansion1.7
D5: ArduinoNano1.8 (D5), Expansion1.8
D6: ArduinoNano1.9 (D6), Expansion1.9
D7: ArduinoNano1.10 (D7), Expansion1.10
D8: ArduinoNano1.11 (D8), Expansion1.11
D9: ArduinoNano1.12 (D9), Expansion1.12
D10: ArduinoNano1.13 (D10), Expansion1.13
D11: ArduinoNano1.14 (D11), Expansion1.14
D12: ArduinoNano1.15 (D12), Expansion1.15
D13: ArduinoNano1.16 (D13), Expansion2.1
GND: 5Vin1.2, ArduinoNano1.4 (GND), ArduinoNano1.29 (GND), Expansion1.4, Expansion2.14, GNDBar1.1, GNDBar1.2, GNDBar1.3, GNDBar1.4, GNDBar1.5, GNDBar1.6, GNDBar1.7, GNDBar1.8, GNDBar1.9, GNDBar1.10, powerIN2.2
RST: ArduinoNano1.3 (~RESET), ArduinoNano1.28 (~RESET), Expansion1.3, Expansion2.13
nano3.3V: ArduinoNano1.17 (3V3), Expansion2.2
nano5V: ArduinoNano1.27 (+5V), Expansion2.12

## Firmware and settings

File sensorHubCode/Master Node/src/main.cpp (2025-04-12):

#include "RF24/RF24.h"
#include "RF24Network/RF24Network.h"
#include "RF24Mesh/RF24Mesh.h"
#include <curl/curl.h>
#include <time.h>
#include <unistd.h>

void sendMetric(CURL *curl, CURLcode res, const char *metric, float value, char *timeSTR);
void updateTime(char *timeSTR, size_t lenSTR);

RF24 radio(22,0);
RF24Network network(radio);
RF24Mesh mesh(radio, network);

typedef struct sensorData_t{
        float tempC;
        float RH;
        float heatIndex;
        float windSpeed;
        float windDirection;
        char initAHT22;
}sensorData_t;

int main(int argc, char** argv){
        const char *metricNames[] = {"Temperature", "Relative Humidity", "Heat Index", "Wind Speed", "Wind Direction"};
        int numberOfMetrics = sizeof(metricNames) / sizeof(metricNames[0]);

        // RF24
        mesh.setNodeID(0);
        radio.begin();
        radio.setPALevel(RF24_PA_MIN, 0);
        // Libcurl
        CURL *curl;
        CURLcode res;
        curl_global_init(CURL_GLOBAL_ALL);
        curl = curl_easy_init();

        char timeSTR[30];

        if(!mesh.begin()){
                printf("Radio hardware not responding.\n");
                return 1;
        }

        printf("Start\n");
        radio.printDetails();

        sensorData_t packet = {0,0,0,0,0,1};
        float* metrics[] = {&packet.tempC, &packet.RH, &packet.heatIndex, &packet.windSpeed, &packet.windDirection};

        while(1){
                mesh.update();
                mesh.DHCP();

                while(network.available()){
                        RF24NetworkHeader header;
                        network.peek(header);

                        updateTime(timeSTR, sizeof(timeSTR));
                        // printf("UTC time is: %s\n",timeSTR);

                        switch(header.type){
                                case 'M':
                                        network.read(header, &packet, sizeof(packet));
                                        //printf("RCV temp_c: %.2f RH: %.2f heatIndex: %.2f wind speed: %.2f wind direction: %.2f from 0%o at UTC time: %s\n", packet.tempC,packet.RH, packet.heatIndex, packet.windSpeed, packet.windDirection,header.from_node, timeSTR);
                                        break;
                                default:
                                        network.read(header, 0, 0);
                                        printf("Rcv bad type %d from 0%o\n", header.type, header.from_node);
                                        break;
                        }
                        printf("Time: %s\n",timeSTR);

                            for(int i = 0; i < numberOfMetrics; i++){
                                if(((metricNames[i] == "Temperature") || (metricNames[i] == "Relative Humidity") || (metricNames[i] == "Heat Index")) && (packet.initAHT22 == 0)){
                                    continue;
                                }
                                sendMetric(curl, res, metricNames[i], *metrics[i], timeSTR);
                                
                                printf("\n");

                                //if(res == CURLE_OK){
                                   // printf("\n");
                                printf("%s: %.2f\n", metricNames[i], *metrics[i]);
                                //}
                            }
                            printf("\n");
                    }
                usleep(5000);
        }
        return 0;
}

void sendMetric(CURL* curl, CURLcode res, const char* metricName, float value, char *timeSTR){
        if(curl) {
                curl_easy_setopt(curl, CURLOPT_URL, "https://api.vinnievertongen.com.au/metrics");
                curl_easy_setopt(curl, CURLOPT_USERPWD, "weathersensor:examplePass");

                // const char *json_data = "{\"bucket\": \"weather-station\", \"org\": \"home\", \"measurement\": \"test-metric\", \"tags\": {\"location\": \"test\"}, \"fields\": {\"value\": 5}, \"timestamp\": \"2024-11-08T08:32:01Z\"}";
                char json_data[1024];
                snprintf(json_data, sizeof(json_data),
                 "{\"bucket\": \"weather-station\", \"org\": \"home\", \"measurement\": \"%s\", "
                 "\"tags\": {\"location\": \"weatherStation\"}, \"fields\": {\"value\": %.2f}, "
                 "\"timestamp\": \"%s\"}",
                 metricName, value, timeSTR);
                curl_easy_setopt(curl, CURLOPT_POSTFIELDS, json_data);
                struct curl_slist *headers = NULL;
                headers = curl_slist_append(headers, "Content-Type: application/json");
                curl_easy_setopt(curl, CURLOPT_HTTPHEADER, headers);
                res = curl_easy_perform(curl);
                if(res != CURLE_OK) {
                        fprintf(stderr, "curl_easy_perform() failed: %s\n", curl_easy_strerror(res));
                }
        }
}

void updateTime(char *timeSTR, size_t lenSTR){
        time_t rawTime;
        struct tm *info;

        time(&rawTime);
        info = gmtime(&rawTime);

        // 2024-11-08T08:32:01Z
        strftime(timeSTR, lenSTR, "%Y-%m-%dT%H:%M:%SZ", info);
}

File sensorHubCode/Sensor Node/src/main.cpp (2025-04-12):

#include <main.h>
#define watchdogCounterTarget 1 //watchdogCounterTarget * 8 seconds = WDT Interrupt Period
volatile int watchdogCounter = 0;

/**** Radio ****/
RF24 radio(CE, CS);
RF24Network network(radio);
RF24Mesh mesh(radio, network);

/**** ANEMOMETER ****/
volatile int revolutionsAnemometerCount;

/**** DHT22 ****/
DHT dht(DHTPIN, DHTTYPE);

sensorData_t packet = {0,0,0,0,0,1};

void setup()
{
  anemometerSetup();
  windVaneSetup();
  Serial.begin(115200);
  while (!Serial){}
  radioSetup();
  dht.begin();
  Serial.println(F("Connected!"));
  watchdogSetup();
  sei();
}

void loop()
{
  if (watchdogCounter >= watchdogCounterTarget){
    radio.powerUp();
    mesh.update();
    getWindspeed(&packet, anemometerArmDistMetres, conversionRatio, &revolutionsAnemometerCount);
    getAHT22(&packet, dht);
    getWindDirection(&packet);
    sendPacket(&packet, 77, sizeof(packet));
    watchdogCounter =0;
    radio.powerDown();
  }
  sleepStation();
}

/**** AUXILIARY FUNCTIONS ****/

void watchdogSetup(){
  // 8s WDT, Interrupt Mode
  MCUSR &= ~(1<<WDRF);
  WDTCSR |= (1<<WDCE) | (1<<WDE);
  WDTCSR = (1<<WDIE) | (1<<WDP3) | (1<<WDP0);
}

void sleepStation(){
  // Enable power-down Mode
  SMCR &= ~((1<<SM0) | (1<<SM2));
  SMCR |= (1<<SM1);
  SMCR |= (1<<SE);
  sleep_cpu();
}

void anemometerSetup()
{
  DDRD &= ~(1 << 2);
  PORTD |= (1 << 2);
  EICRA |= (1 << ISC01);
  EIMSK |= (1 << INT0);
}

void windVaneSetup(){
  DDRD &= ~(1<<Qh);
  DDRD |= (1<<SHLD) | (1<<CLK) | (1<<CLKINH);
  PORTD &= ~(1<< CLKINH);
}

void radioSetup()
{
  mesh.setNodeID(nodeID);
  radio.begin();
  radio.setPALevel(RF24_PA_MIN, 0);

  Serial.println(F("Connecting to the mesh..."));
  if (!mesh.begin())
  {
    if (radio.isChipConnected())
    {
      do
      {
        // mesh.renewAddress() will return MESH_DEFAULT_ADDRESS on failure to connect
        Serial.println(F("Could not connect to network.\nConnecting to the mesh..."));
      } while (mesh.renewAddress() == MESH_DEFAULT_ADDRESS);
    }
    else
    {
      Serial.println(F("Radio hardware not responding."));
      while (1)
      {
      }
    }
  }
}

void sendPacket(sensorData_t *packet, uint8_t msg_type, size_t packetSize)
{
  if (!mesh.write(packet, msg_type, packetSize))
  {
    // If a write fails, check connectivity to the mesh network
    if (!mesh.checkConnection())
    {
      // refresh the network address
      Serial.println("Renewing Address");
      if (mesh.renewAddress() == MESH_DEFAULT_ADDRESS)
      {
        // If address renewal fails, reconfigure the radio and restart the mesh
        // This allows recovery from most if not all radio errors
        mesh.begin();
      }
    }
  }
}

void getWindspeed(sensorData_t *packet, float anemometerArmDistMetres, float conversionRatio, volatile int* revolutionsAnemometerCount){
  float speed = anemometerArmDistMetres * (conversionRatio * (((float)*revolutionsAnemometerCount / (float)(watchdogCounterTarget*8)) * (float)60));
  *revolutionsAnemometerCount = 0;
  packet->windSpeed = speed;
}

void getAHT22(sensorData_t *packet, DHT dhtSensor){
  packet->RH = dhtSensor.readHumidity();
  packet->tempC = dhtSensor.readTemperature();
  packet->heatIndex =dhtSensor.computeHeatIndex(false);
  if (isnan(packet->RH) || isnan(packet->tempC) || isnan(packet->heatIndex)) {
    packet->initAHT22 = false;
  }else{
    packet->initAHT22 = true;
  }
}

void getWindDirection(sensorData_t *packet){
  uint8_t data = 0;
  PORTD &= ~(1<<SHLD);
  delayMicroseconds(1);
  PORTD |= (1<<SHLD);
  
  for(int i = 0; i < 8; i++){
    PORTD |= (1<<CLK);
    delayMicroseconds(1);
    data |= ((PIND & (1 << Qh)) ? 0 : 1) << (7 - i);
    PORTD &= ~(1<<CLK);
  }
  packet->windDirection = (float)data;
}

ISR(INT0_vect)
{
  revolutionsAnemometerCount += 1;
}

ISR(WDT_vect){
  watchdogCounter += 1;
}

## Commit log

2024-10-11 Updated BOM
    [BOM.ods]
2024-10-14 Added magnet cost
    [BOM.ods]
2024-10-14 Updated BOM materials
    [BOM.ods]
2024-10-21 Update Main.cpp
    Moved include files to main.h and modified code to read data from AHT20, and LPS331AP.
    Currenly can only read one sensor at a time and data casted to UINT32 as master node has not been configured for multiple inputs and float data.
2024-10-22 Raspberry Pi branch for MAKEFILE testing.
2024-10-23 Modifed main.cpp and created Makefile main.cpp now should now work with raspberry pi zero 2 w if the rf24libs have been installed correctly to ~/rf24libs (default). Ensure the rf24 installation scrip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
    [main.cpp]
2024-10-23 Altered main to read data sent from all sensors.
2024-10-23 Updated sensor to send packet data
2024-10-23 Added Arduino Nano to BOM
    [BOM.ods]
2024-11-10 POST sensor data
2024-11-20 CAD UPDATES
    [90Degree.FCStd, adapter.FCStd, adapterRing.FCStd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]
2024-11-21 kiCAD files
    [BOM.ods, anemometer.kicad_pcb, anemometer.kicad_sch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]
2024-11-22 Electrical Schematic Updates
    [BOM.ods, electricalConnections.ods, windVane.kicad_pcb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]
2024-11-25 Update Schematics
    [BOM.ods, anemometer.kicad_sch, arduino.kicad_pcb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]
2024-11-26 Updated Circuit Diagram
2024-11-27 Cross checked schematic with diagram layout
2024-11-27 Created power system schematic
    [powerSystem.kicad_pcb, powerSystem.kicad_sch]
2024-12-03 Big Updates
    [arduino.kicad_pcb, arduino.kicad_sch, assembley.FCStd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]
2025-02-10 Big Updates Good Luck
    [5vStepDownStandoff-Body.stl, 5vStepDownStandoff.FCStd, 5vStepDownStandoff2-Body.stl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]
2025-02-10 Temp fix of hanging sensor
    - Enabled Timeouts in twi.c and Wire_timeout.h
    - Temp error checking handled in main.cpp
    Ideally break the main loop into individual function calls so that if a sensor is lost it can just be ignored.
    [main.cpp]
2025-02-11 Created sendPacket(); fixed windspeed delay
    Created sendPacket() function that accepts a generic structure and sends it via RF.
    Used to send different data packets with same function call.
    Wrapped "aht20.getMeasurement()" with initAHT20 as it would delay the ISR when AHT20 in a non functioning state otherwise.
    [main.cpp]
2025-02-12 Added getWindSpeed function
    Simple function that stores the windspeed calculated directly into data packet.windSpeed.
    Commented out getAHT20Data as it causes issues with sending data.
    [main.cpp]
2025-02-12 fixed getAHT20Data; code tidy
    [main.cpp]
2025-02-13 Updated sendPacket and getWindSpeed
    - Changed sendPacket to accept a sensorData_t type for debugging purpose.
    - getWindSpeed can now directly alter the values of the struct similar to other functions.
2025-02-13 Updated main.cpp
    - Add float limits to print statement
    - Changed the declaration of structure to match C format
2025-02-14 Added sensor verifcation method before posting data to webserver
2025-02-14 Post no data if CURL failed
    [main.cpp]
2025-02-14 Added sensor verification methods to packet data
2025-02-23 Code Refactor; Removed Blocking Time Interval
    - Dedicated setup functions for different parts of the system.
    - Software timer now used to send a packet X seconds rather than a blocking time difference check. Done to mitigate chances of blocking code interfering with interrupts.
    [main.cpp]
2025-03-06 Updated sensor code
    Removed LPS, AHT20 sensors
    Added DHT22 sensor
2025-03-06 Updated for 4 solar panels
    [singlePieceFrame-Single Piece Solar Frame.stl, singlePieceFrame.FCStd, solarBedFrame-Solar Bed.stl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]
2025-03-06 Added DHT22, removed AHT20/LPS
    [ioList.ods]
2025-03-06 removed AHT20/LPS sensor; added AHT22 sensor
2025-04-12 Switched software timer to WDT, optimized power consumption from 64 mA @ 3.7V to 21 mA @ 3.7V
